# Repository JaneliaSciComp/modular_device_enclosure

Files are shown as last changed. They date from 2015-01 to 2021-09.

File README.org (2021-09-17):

#+TITLE: modular_device_enclosure
#+AUTHOR: Peter Polidoro
#+EMAIL: peter@polidoro.io

* Repository Information

  - Name :: modular_device_enclosure
  - License :: Open-Source Hardware
  - URL :: https://github.com/janelia-modular-devices/modular_device_enclosure
  - Author :: Peter Polidoro
  - Email :: peter@polidoro.io

** Description

   This repository contains the files for constructing enclosures for modular
   devices.

* Assembly Instructions

  - Count modular devices of each form factor for a particular setup and choose
    the appropriate dxf file.
  - Choose appropriate size of 0.125 inch thick acrylic sheet and cut out dxf
    file using a laser cutter.
  - Press captive nuts into each of the small mounting holes.
  - Insert one 0.375 inch cap screw into each hole on the modular device base
    pcb marked with a white circle and screw a round threaded standoff onto the
    other side.
  - Align header pins of the top pcb with the sockets of the modular device base
    and press the top pcb onto the base until it is firmly seated.
  - On the 5x3 form factor modular devices, place one of the round unthreaded
    spacers between the top pcb and the base pcb at the two mounting holes
    furthest from the header pins.
  - Place one nylon washer onto each of the 1.25 inch cap screws and insert one
    of the screws with a washer into each of the mounting holes on the top pcb
    marked with a white circle.
  - Align the 1.25 inch cap screws with the captive nuts pressed into the
    acrylic and screw each one in firmly, but not so tightly as to bend the
    acrylic.

* Bill of Materials

** Enclosure Parts

   [[file:./bom/bom.org]]

** Supplemental Parts

   [[file:./bom/supplemental_bom.org]]

** Vendor Parts Lists

   [[file:./bom/digikey_parts.org]]

   [[file:./bom/mcmaster_parts.org]]

* DXF Files

** Single Modular Device

*** 3x2 Form Factor

    [[file:./3x2/dxf/enclosure_bottom.dxf]]

*** 5x3 Form Factor

    [[file:./5x3/dxf/enclosure_bottom.dxf]]

** Multiple Modular Devices

*** 3x2 Form Factor

    [[file:./multiple/3x2x2.dxf]]

    [[file:./multiple/3x2x3.dxf]]

    [[file:./multiple/3x2x4.dxf]]

*** 5x3 Form Factor

    [[file:./multiple/5x3x2.dxf]]

    [[file:./multiple/5x3x3.dxf]]

    [[file:./multiple/5x3x4.dxf]]

*** Both 3x2 and 5x3 Form Factors

    [[file:./multiple/5x3x1_3x2x1.dxf]]

    [[file:./multiple/5x3x1_3x2x2.dxf]]

    [[file:./multiple/5x3x1_3x2x3.dxf]]

    [[file:./multiple/5x3x1_3x2x4.dxf]]

    [[file:./multiple/5x3x2_3x2x1.dxf]]

    [[file:./multiple/5x3x2_3x2x2.dxf]]

    [[file:./multiple/5x3x2_3x2x3.dxf]]

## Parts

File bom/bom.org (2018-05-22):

* Bill of Materials
#+RESULTS: enclosure-parts
| Item | Quantity | PartNumber     | Vendor   | Description                                                                        |
|------+----------+----------------+----------+------------------------------------------------------------------------------------|
|    1 |        8 | 92196A108      | mcmaster | 18-8 Stainless Steel Socket Head Cap Screw 4-40 Thread 0.375 inch Length           |
|    2 |        8 | 92196A302      | mcmaster | 18-8 Stainless Steel Socket Head Cap Screw 4-40 Thread 1.25 inch Length            |
|    3 |        8 | 90295A340      | mcmaster | Nylon 6/6 General Purpose Flat Washer Number 4 Screw Size .21in OD .04-.06in Thick |
|    4 |        8 | 94648A320      | mcmaster | 18-8 Stainless Steel Broach Style Captive Nut 4-40 Thread Size                     |
|    5 |        1 | 8560K239       | mcmaster | Optically Clear Cast Acrylic Sheet 0.125 inch thick 12x12 inch                     |
|    6 |        1 | 8560K257       | mcmaster | Optically Clear Cast Acrylic Sheet 0.125 inch thick 12x24 inch                     |
|    7 |        2 | 492-1077-ND    | digikey  | ROUND SPACER #4 NYLON 7/16 inch                                                    |
|    8 |        4 | A9CCA-0202F-ND | digikey  | FLEX CABLE - AFG02A/AF02/AFG02A                                                    |
|    9 |        4 | A9CCA-0302F-ND | digikey  | FLEX CABLE - AFG03A/AF03/AFG03A                                                    |

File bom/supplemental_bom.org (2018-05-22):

* Supplemental Bill of Materials
#+RESULTS: supplemental-parts
| Item | Quantity | PartNumber | Vendor   | Description                             |
|------+----------+------------+----------+-----------------------------------------|
|    1 |        1 | 502PV-ND   | digikey  | HAND PRESS BENCH MOUNT                  |
|    2 |        1 | 506PV-ND   | digikey  | HAND PRESS IDC CONVERSION KIT           |
|    3 |        1 | 510PV-ND   | digikey  | BASE PLATE SOCKET IDC                   |
|    4 |        1 | 6493A91    | mcmaster | Ultra-Gold Hex L-Keys 13-Piece Inch Set |

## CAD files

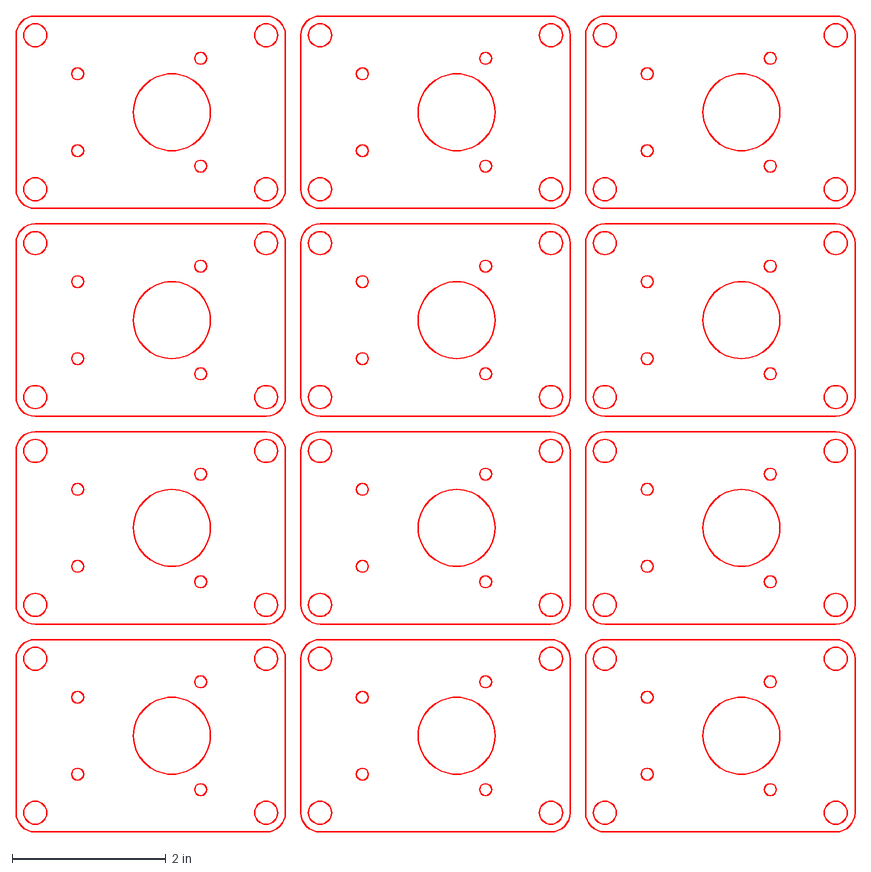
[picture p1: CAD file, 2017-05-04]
3x2/dxf/enclosure_bottom_lc.dxf
10.9 x 10.6 in

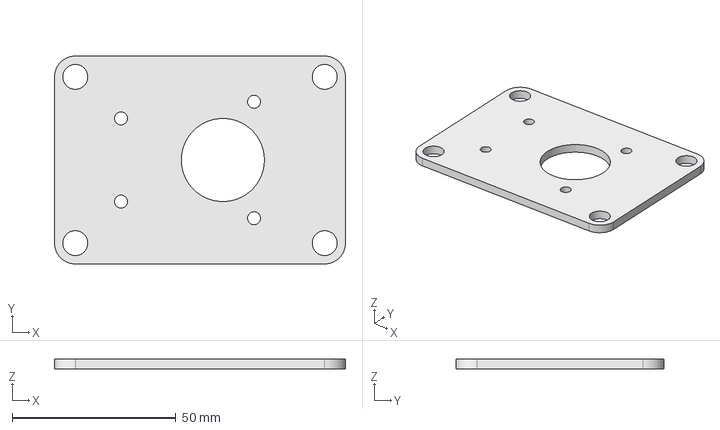
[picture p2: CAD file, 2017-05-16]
3x2/freecad/enclosure_bottom.fcstd
88.9 x 63.5 x 3.17 mm

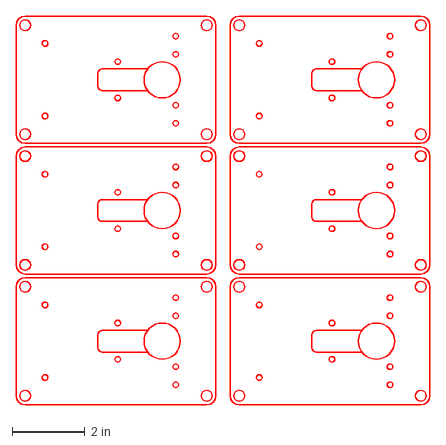
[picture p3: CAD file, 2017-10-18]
5x3/dxf/enclosure_bottom_lc.dxf
11.4 x 10.7 in

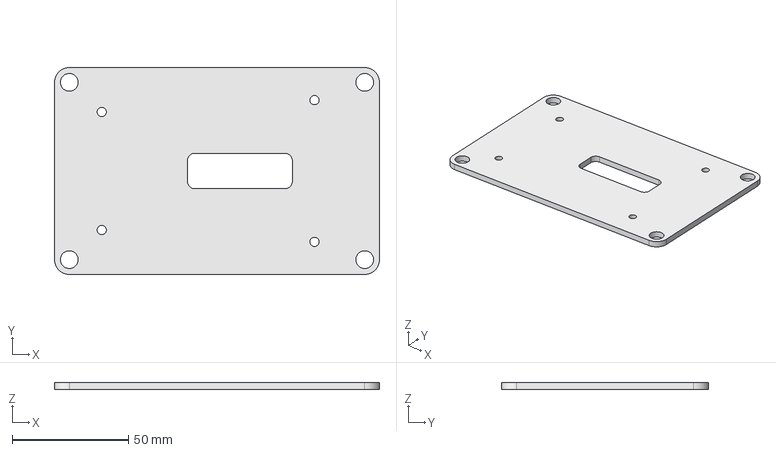
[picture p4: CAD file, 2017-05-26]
5x3/freecad/enclosure_bottom.fcstd
139.7 x 88.9 x 3.17 mm

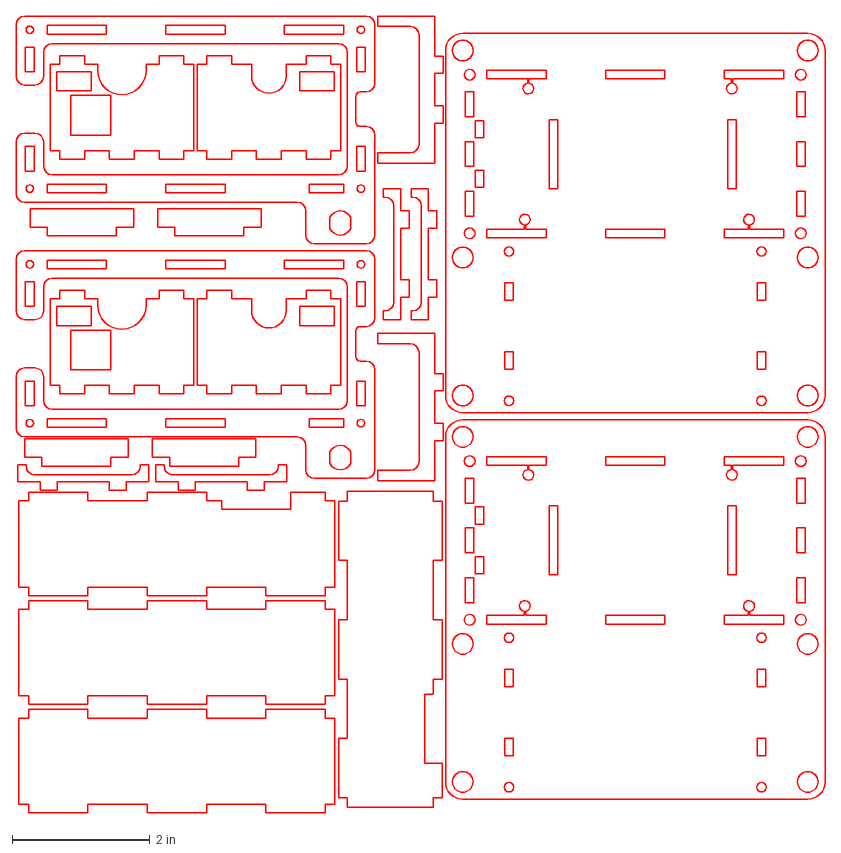
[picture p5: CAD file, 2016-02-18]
dxf/laser_cutter_0.125in_display.dxf
11.7 x 11.6 in

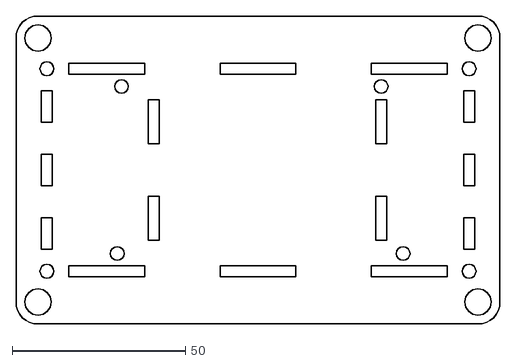
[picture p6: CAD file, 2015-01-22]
enclosure_bottom.dxf
139.7 x 88.9

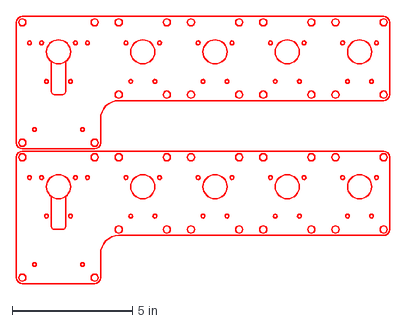
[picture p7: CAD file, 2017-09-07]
multiple/5x3x1_3x2x4_lc.dxf
15.5 x 11.1 in

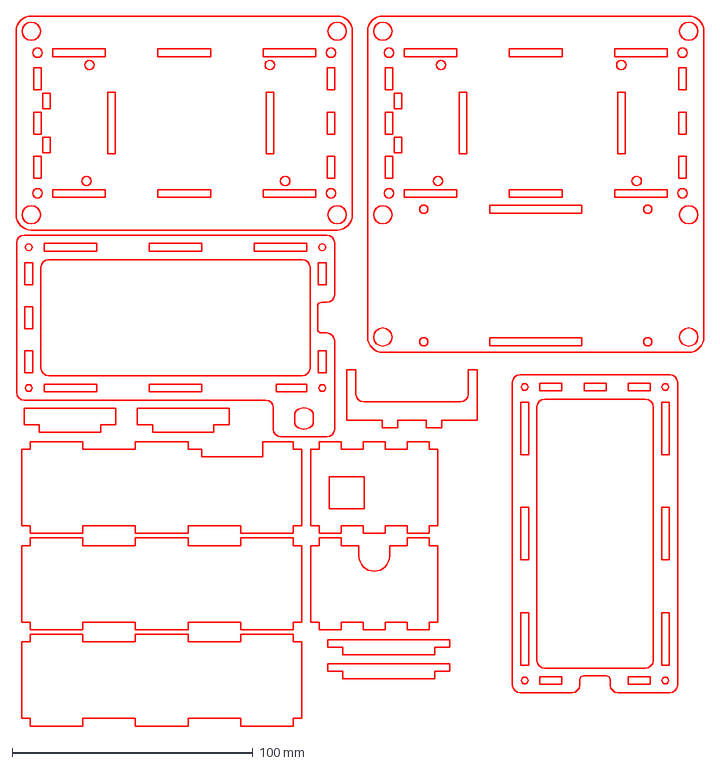
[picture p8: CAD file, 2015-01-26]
dxf/laser_cutter_0.125.dxf
285.7 x 294.9 mm

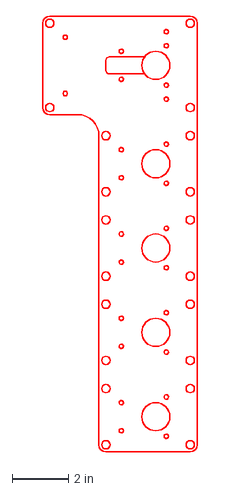
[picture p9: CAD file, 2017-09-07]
multiple/5x3x1_3x2x4.dxf
5.50 x 15.5 in

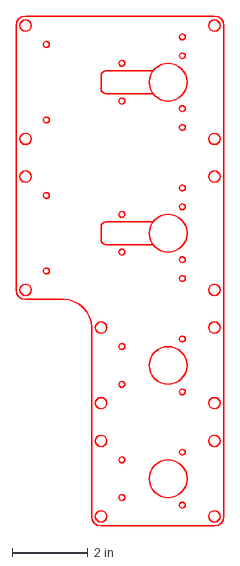
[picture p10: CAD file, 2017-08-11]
multiple/5x3x2_3x2x2.dxf
5.50 x 13.5 in

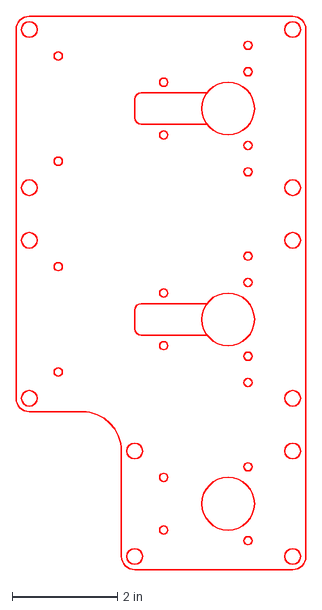
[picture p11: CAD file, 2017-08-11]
multiple/5x3x2_3x2x1.dxf
5.50 x 10.5 in

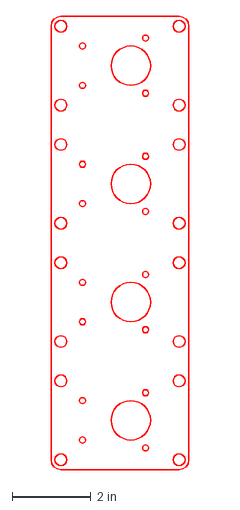
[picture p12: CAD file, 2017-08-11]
multiple/3x2x4.dxf
3.50 x 11.5 in

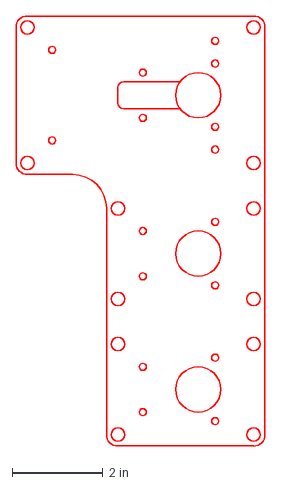
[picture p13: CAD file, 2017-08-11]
multiple/5x3x1_3x2x2.dxf
5.50 x 9.50 in

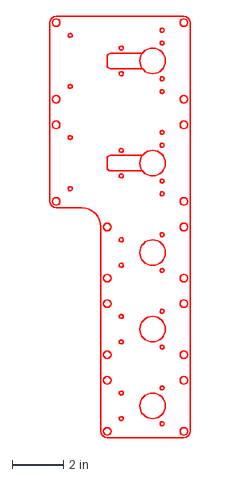
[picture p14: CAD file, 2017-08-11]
multiple/5x3x2_3x2x3.dxf
5.50 x 16.5 in

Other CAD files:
multiple/5x3x1_3x2x1.dxf
multiple/5x3x1_3x2x1_lc.dxf
multiple/5x3x1_3x2x3_lc.dxf
multiple/5x3x1_3x2x3.dxf
3x2/dxf/enclosure_bottom.dxf
5x3/dxf/enclosure_bottom.dxf
laser_cutter_0.125.dxf
multiple/3x2x2.dxf
multiple/3x2x3.dxf
multiple/3x2x3_lc.dxf
multiple/5x3x2.dxf
multiple/5x3x2_lc.dxf
multiple/5x3x3.dxf
multiple/5x3x4.dxf
multiple/5x3x4_lc.dxf

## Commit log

2015-01-22 Added arduino mega2560 3D CAD file.
    [arduino_mega2560.fcstd]
2015-01-22 Finished basics of arduino_mega2560.
    [arduino_mega2560.fcstd]
2015-01-22 Initial commit of enclosure_bottom.
    [enclosure_bottom.fcstd]
2015-01-22 Finished enclosure_bottom.
    [enclosure_bottom.fcstd]
2015-01-22 Completed enclosure_left and enclosure_right.
    [enclosure_bottom.dxf, enclosure_left.dxf, enclosure_left.fcstd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]
2015-01-23 Initial enclosure_front commit.
    [enclosure_bottom.fcstd, enclosure_front.fcstd]
2015-01-23 Finished enclosure_front. Initial add of new files.
    [enclosure_back.fcstd, enclosure_bottom.fcstd, enclosure_front.fcstd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]
2015-01-23 Finished enclosure_back.
    [enclosure_back.fcstd]
2015-01-23 Initial enclosure_top design.
    [enclosure_top.fcstd]
2015-01-23 Finished enclosure_top.
    [enclosure_top.fcstd]
2015-01-23 Finished enclosure_top_encoder.
    [enclosure_right_encoder.fcstd, enclosure_top_encoder.fcstd]
2015-01-23 Finished enclosure_spacer_short.
    [enclosure_bottom.fcstd, enclosure_spacer_short.fcstd]
2015-01-23 Finished enclosure_spacer_tall.
    [enclosure_spacer_short.fcstd, enclosure_spacer_tall.fcstd]
2015-01-23 Added dxf files.
    [enclosure_back.dxf, enclosure_front.dxf, enclosure_right_encoder.dxf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]
2015-01-23 Added laser_cutter file.
    [laser_cutter_0.125.dxf]
2015-01-23 Finished enclosure_bottom_display.
    [enclosure_bottom.fcstd, enclosure_bottom_display.fcstd]
2015-01-23 Finished enclosure_spacer_display.
    [enclosure_bottom_display.fcstd, enclosure_spacer_display.fcstd]
2015-01-23 Added enclosure_bottom_display to laser_cutter file.
    [enclosure_bottom_display.dxf, enclosure_spacer_display.dxf, laser_cutter_0.125.dxf]
2015-01-26 Reorganized files.
    [arduino_mega2560.fcstd, enclosure_back.dxf, enclosure_back.fcstd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]
2015-01-26 Changed units to inches.
    [laser_cutter_0.125in.dxf]
2015-01-27 Changed display spacer and cut holes to add relief from captive nuts.
    [enclosure_bottom.dxf, enclosure_bottom.fcstd, enclosure_bottom_display.dxf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]
2015-01-27 Added bom.
    [bom.csv]
2015-01-27 Finished power_switch_controller.
    [enclosure_front.dxf, enclosure_front.fcstd, enclosure_top.dxf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]
2015-09-10 Added display only enclosure version.
    [laser_cutter_0.125in_display.dxf, laser_cutter_0.125in_full.dxf]
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2015-09-30 Initial assembly instructions.
    [bom_pcb_add.csv]
2015-09-30 Added more assembly instructions.
    [bom_pcb_add.csv]
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2015-09-30 Moved parts to bom.
    [bom.csv, bom_pcb_add.csv]
2016-02-17 Added holes for uart connectors.
    [enclosure_back.dxf, enclosure_back.fcstd, enclosure_front.dxf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]
2016-02-18 Added more room for USB connector.
    [enclosure_front.dxf, enclosure_front.fcstd, enclosure_spacer_tall.dxf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]
2016-03-09 New serial connectors.
    [enclosure_back.dxf, enclosure_back.fcstd, enclosure_bottom.dxf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]
2016-03-09 Added hole in enclosure_right.
    [enclosure_right.dxf, enclosure_right.fcstd, laser_cutter_0.125in.dxf]
2016-03-09 Widened serial connector holes.
    [enclosure_back.dxf, enclosure_back.fcstd, enclosure_front.dxf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]
2016-07-20 Made enclosure_left symmetric.
    [enclosure_left.dxf, enclosure_left.fcstd, laser_cutter_0.125in.dxf]
2016-07-25 Created directories for different form factors.
    [arduino_mega2560.fcstd, bom.csv, bom_pcb_add.csv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]
2016-07-25 Initial commit of teensy enclosure file.
    [enclosure_bottom.fcstd]
2016-07-25 First attempt at teensy enclosure.
    [enclosure_bottom.dxf, enclosure_bottom.fcstd]
2016-08-16 Moved mounting holes to match new pcb layout.
    [enclosure_bottom.dxf, enclosure_bottom.fcstd]
2016-08-16 Made dxf layer red with 0 width.
    [enclosure_bottom.dxf]
2016-08-29 Changed units to mm and made array file.
    [laser_cutter_0.125in.dxf]
2017-05-04 Renamed directory.
    [enclosure_bottom.dxf, enclosure_bottom.fcstd, laser_cutter_0.125in.dxf]
2017-05-04 Added 5x3.
    [enclosure_bottom.dxf, enclosure_bottom.fcstd, laser_cutter_0.125in.dxf]
2017-05-04 Added multiple.
    [3x2x2.dxf, 3x2x3.dxf, 3x2x3_lc.dxf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]
2017-05-04 Updated 3x2.
    [enclosure_bottom.dxf, enclosure_bottom_lc.dxf]
2017-05-04 Added multiples.
    [3x2x2.dxf, 3x2x3.dxf, 3x2x3_lc.dxf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]
2017-05-16 5x3 first pass.
    [enclosure_bottom.dxf, enclosure_bottom.fcstd]
2017-05-17 Added 3x2 to 5x3.
    [enclosure_bottom.dxf]
2017-05-26 Moved aluminum standoffs to modular_device_base bom.
    [bom.csv, digikey_order.csv]
2017-05-26 Updated mounting hole placement.
    [enclosure_bottom.dxf, enclosure_bottom.fcstd]
2017-07-06 Added multiple 5x3.
    [5x3x2.dxf, 5x3x3.dxf]
2017-07-06 Added 5x3x2_lc.
    [5x3x2_lc.dxf]
2017-07-06 Added 5x3x4.
    [5x3x4.dxf, 5x3x4_lc.dxf, bom.csv]
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2017-08-11 Added several multiple options.
    [3x2x4.dxf, 5x3x1_3x2x2.dxf, 5x3x2_3x2x1.dxf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]
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2017-09-07 Added laser cutter version.
    [5x3x1_3x2x4_lc.dxf]
2017-10-18 Switch units from mm to inch.
    [enclosure_bottom_lc.dxf]
2017-10-18 Switched to correct part.
    [enclosure_bottom_lc.dxf]
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2018-05-22 Updated bom files and README.
    [bom.csv, bom_add.csv, digikey_parts.csv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]
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
